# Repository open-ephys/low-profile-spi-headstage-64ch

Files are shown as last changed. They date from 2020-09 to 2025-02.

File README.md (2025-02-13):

# Low-profile SPI Headstage with 64 ephys channels

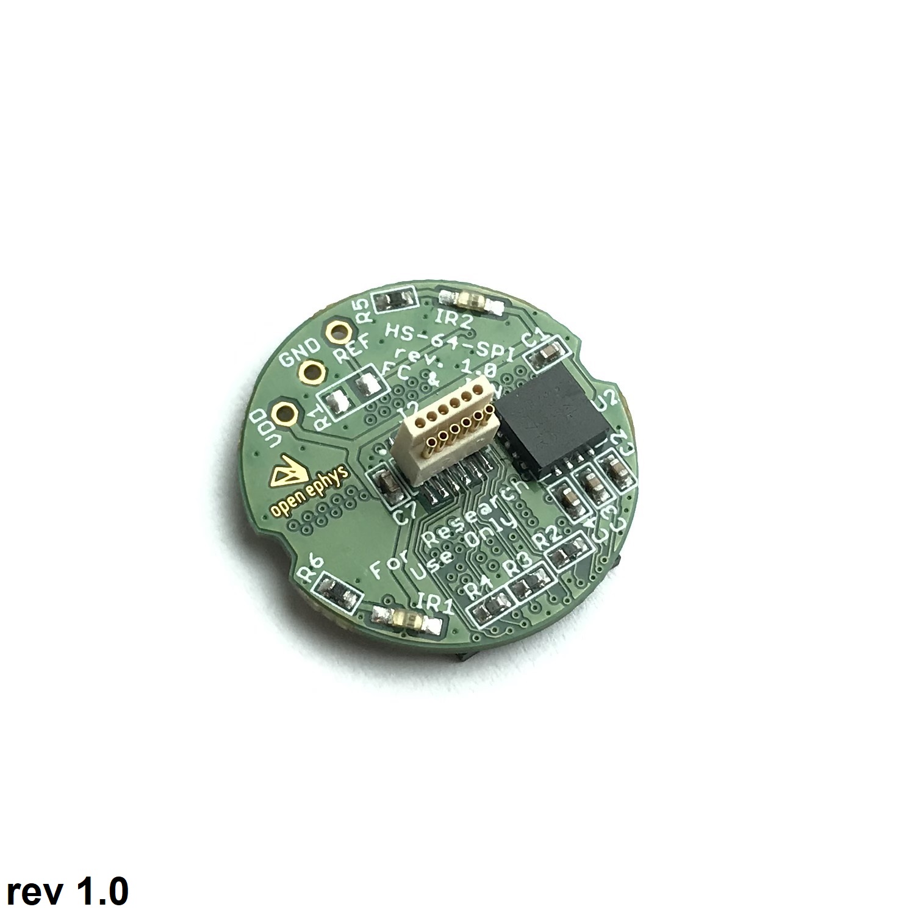
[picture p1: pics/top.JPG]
DeviceTop


## Accelerometer orientation
LP_headstage_top_accelerometer_v1 00

## Licensing

The designs, documentation, and photos available in this repository are free: you can redistribute it and/or modify it under the terms of the used license.
Check file named LICENSE.

Copyright Filipe Carvalho and Jonathan Newman 2020-2022

<br />This work is licensed under a <a rel="license" href="http://creativecommons.org/licenses/by-nc-sa/3.0/igo/">Creative Commons Attribution-NonCommercial-ShareAlike 3.0 IGO License</a>.

If your are interested in obtaining a license to sell this device, please contact info@open-ephys.org

[1]: https://docs.google.com/spreadsheets/d/1aobmmEzBDethzIlrm1eg0eYkBqlyX3s9WbA9KgRwVQI/edit?usp=sharing

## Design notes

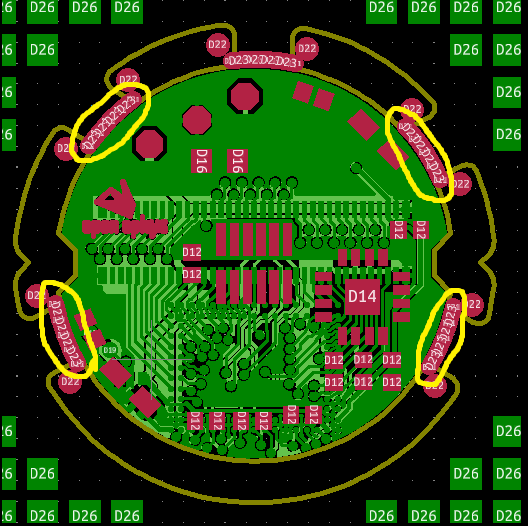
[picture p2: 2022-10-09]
production/mouse bites suggested locations.png

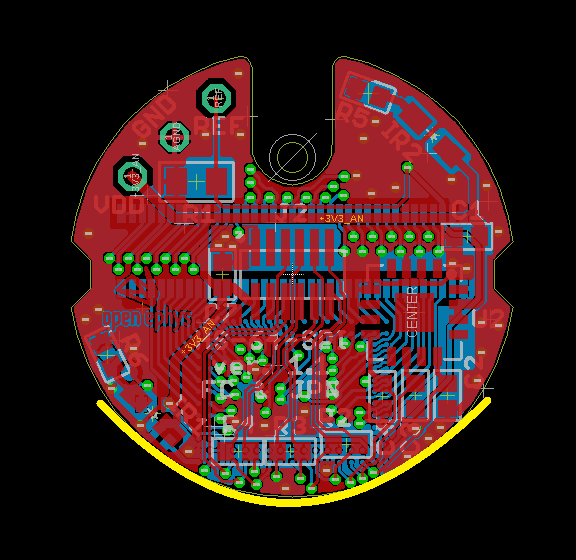
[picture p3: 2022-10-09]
production/mouse bites restriction.png

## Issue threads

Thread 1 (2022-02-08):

Noise

crewl2, 2022-02-08:
I'm getting a ton of noise, I'm wondering if it is coming from the headstage. Should the headstage be grounded?

jonnew, 2022-02-10:
Hi. Yes, it will need to be grounded in order to complete the electrical circuit. I'm not trying to be rude, but you question is indicates that you might need some help setting up your system and understanding the basics of extracellular recordings. I would have a look through this excellent set of materials put together by @ahleighton on how ephys works https://ahleighton.github.io/OE-ephys-course/EEA/theoryday1.html. Also if there is somebody in your lab that has done this type of recording before, I would talk with them about your issue.

Closed 2022-02-10.

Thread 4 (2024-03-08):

Pictures are of v1.0 when current release is v1.1

ChucklesOnGitHub, 2024-03-08:
There is a major difference in GND and REF being connected in v1.1 as opposed to v1.0
And the added cannula hole

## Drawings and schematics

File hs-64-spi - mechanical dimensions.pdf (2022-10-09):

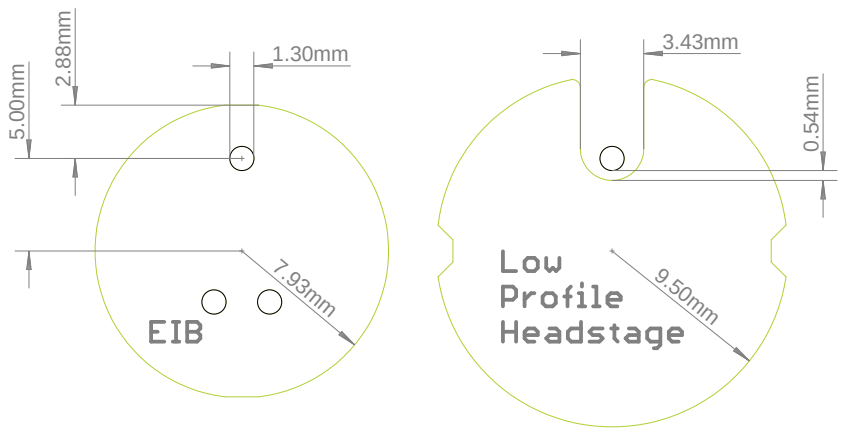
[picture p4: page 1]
9.50mm ³mm

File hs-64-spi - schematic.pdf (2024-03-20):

# AGND AGND ¹

M1

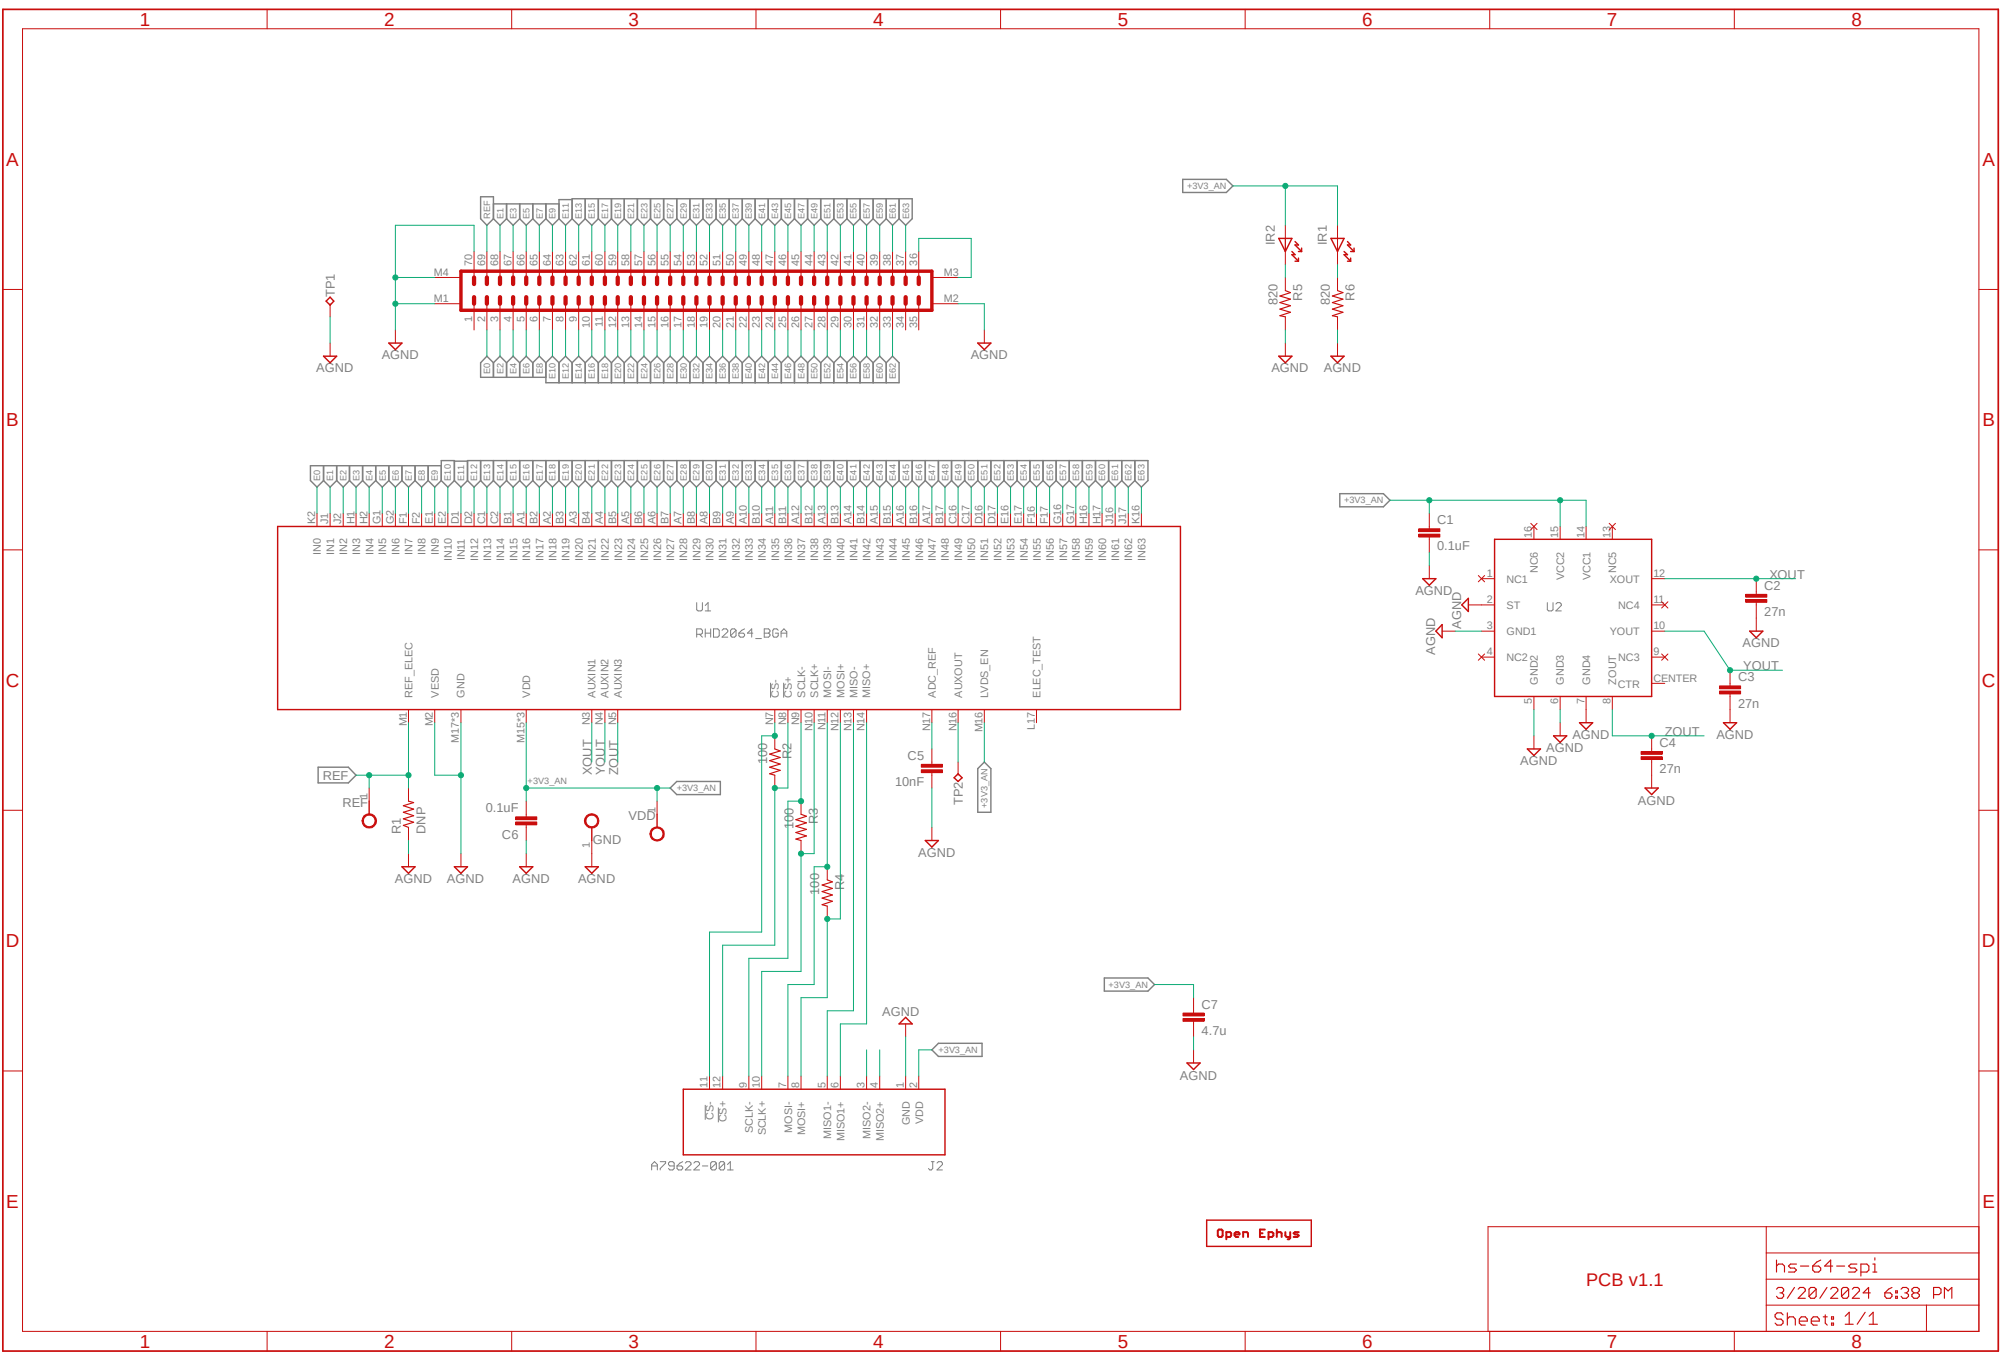
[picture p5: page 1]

8 MOSI- 7 SCLK+ 10 SCLK- 9 VDD

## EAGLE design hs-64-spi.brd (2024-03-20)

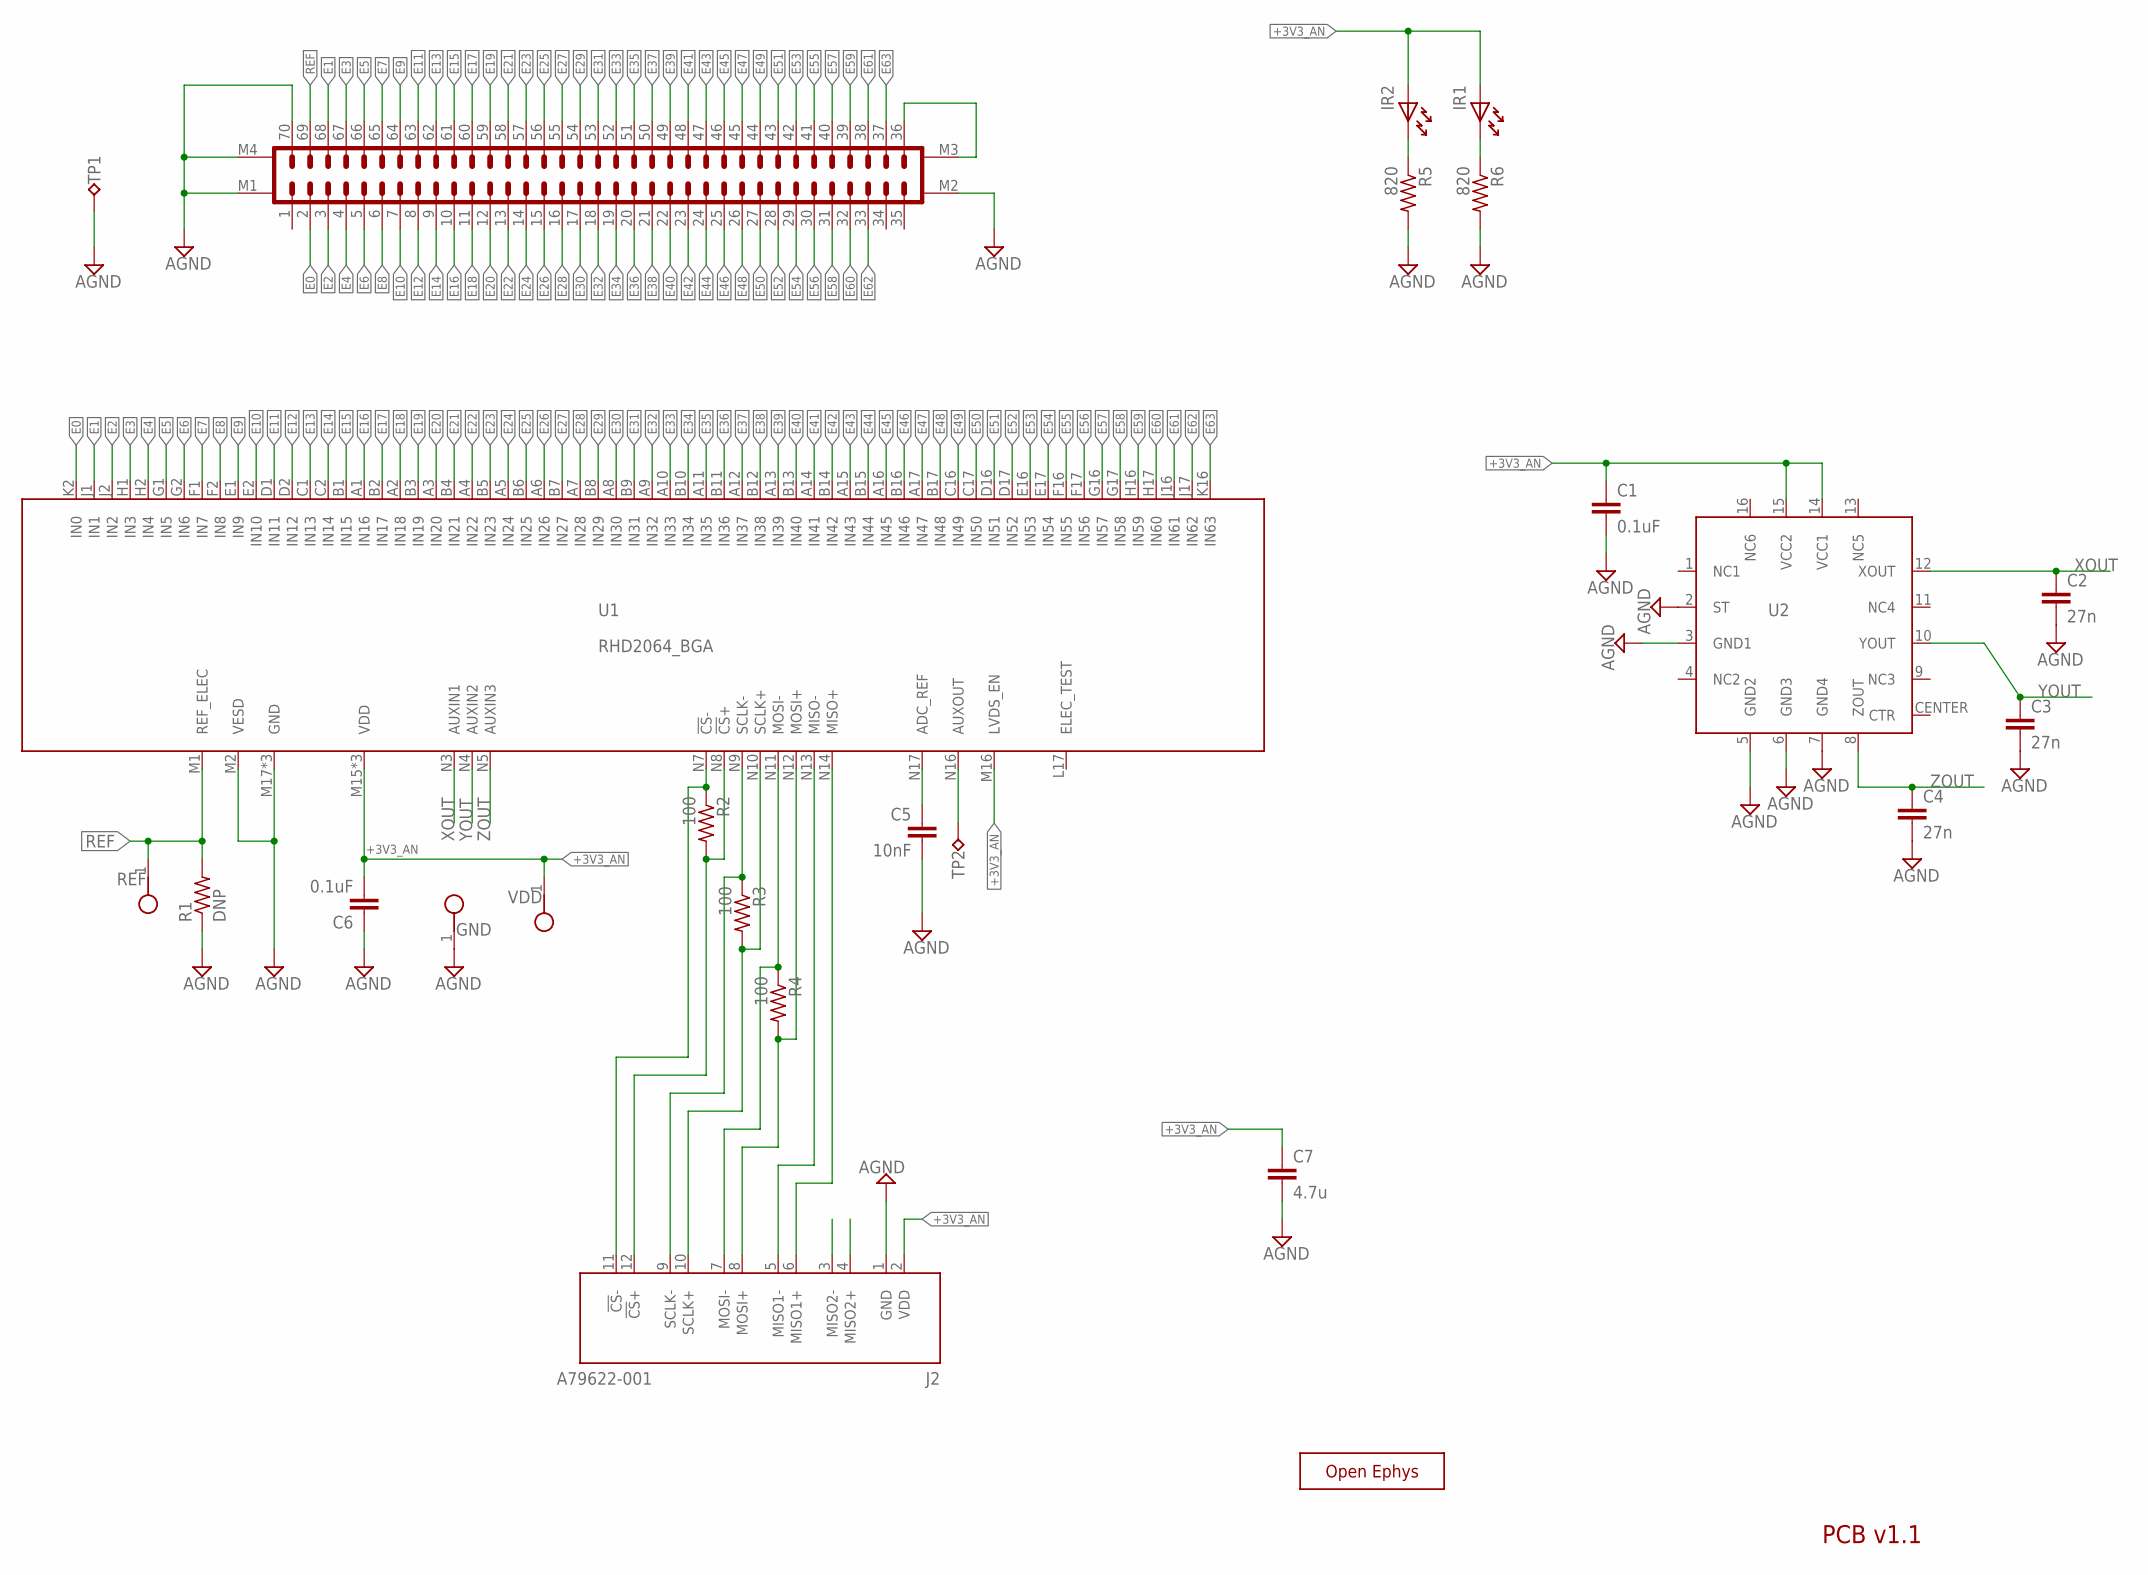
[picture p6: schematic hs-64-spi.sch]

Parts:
C1: 0.1uF; 0402
C2, C3, C4: 27n; 0402
C5: 10nF; 0402T; PARTNO GRM033R71E103KE14D
C6: 0.1uF; 0402T
C7: 4.7u; 0402
GND: TESTPOINT_SMALL
IR1, IR2: LEDHAND; LED_HAND
J1: DF40C-70DP-0.4V(51); DF40-70HEAD-LESS-SILK
J2: A79622-001
R1: DNP; 0603
R2, R3, R4: 100; 0402
R5, R6: 820; 0402
REF: TESTPOINT_SMALL
TP1, TP2: VCC; TP07R
U1: RHD2064_BGA; BGA104_0.5MM
U2: ADXL335_IDAX
VDD: TESTPOINT_SMALL
X: OE-LOGO_3.5X2.5; OE-LOGO-3.5X2.5

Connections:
+3V3_AN: C1.1, C6.2, C7.1, IR1.A, IR2.A, J2.2 (VDD), U1.M15 (VDD), U1.M16 (LVDS_EN), U1.N2 (VDD), U1.N15 (VDD), U2.14 (VCC1), U2.15 (VCC2), VDD.1
AGND: C1.2, C2.2, C3.2, C4.2, C5.2, C6.1, C7.2, GND.1, J1.70, J1.M1, J1.M2, J1.M4, J2.1 (GND), R1.1, R5.2, R6.2, TP1.TP, U1.M2 (VESD), U1.M17 (GND), U1.N1 (GND), U1.N6 (GND), U2.2 (ST), U2.3 (GND1), U2.5 (GND2), U2.6 (GND3), U2.7 (GND4)
E0: J1.2, U1.K2 (IN0)
E1: J1.68, U1.J1 (IN1)
E2: J1.3, U1.J2 (IN2)
E3: J1.67, U1.H1 (IN3)
E4: J1.4, U1.H2 (IN4)
E5: J1.66, U1.G1 (IN5)
E6: J1.5, U1.G2 (IN6)
E7: J1.65, U1.F1 (IN7)
E8: J1.6, U1.F2 (IN8)
E9: J1.64, U1.E1 (IN9)
E10: J1.7, U1.E2 (IN10)
E11: J1.63, U1.D1 (IN11)
E12: J1.8, U1.D2 (IN12)
E13: J1.62, U1.C1 (IN13)
E14: J1.9, U1.C2 (IN14)
E15: J1.61, U1.B1 (IN15)
E16: J1.10, U1.A1 (IN16)
E17: J1.60, U1.B2 (IN17)
E18: J1.11, U1.A2 (IN18)
E19: J1.59, U1.B3 (IN19)
E20: J1.12, U1.A3 (IN20)
E21: J1.58, U1.B4 (IN21)
E22: J1.13, U1.A4 (IN22)
E23: J1.57, U1.B5 (IN23)
E24: J1.14, U1.A5 (IN24)
E25: J1.56, U1.B6 (IN25)
E26: J1.15, U1.A6 (IN26)
E27: J1.55, U1.B7 (IN27)
E28: J1.16, U1.A7 (IN28)
E29: J1.54, U1.B8 (IN29)
E30: J1.17, U1.A8 (IN30)
E31: J1.53, U1.B9 (IN31)
E32: J1.18, U1.A9 (IN32)
E33: J1.52, U1.A10 (IN33)
E34: J1.19, U1.B10 (IN34)
E35: J1.51, U1.A11 (IN35)
E36: J1.20, U1.B11 (IN36)
E37: J1.50, U1.A12 (IN37)
E38: J1.21, U1.B12 (IN38)
E39: J1.49, U1.A13 (IN39)
E40: J1.22, U1.B13 (IN40)
E41: J1.48, U1.A14 (IN41)
E42: J1.23, U1.B14 (IN42)
E43: J1.47, U1.A15 (IN43)
E44: J1.24, U1.B15 (IN44)
E45: J1.46, U1.A16 (IN45)
E46: J1.25, U1.B16 (IN46)
E47: J1.45, U1.A17 (IN47)
E48: J1.26, U1.B17 (IN48)
E49: J1.44, U1.C16 (IN49)
E50: J1.27, U1.C17 (IN50)
E51: J1.43, U1.D16 (IN51)
E52: J1.28, U1.D17 (IN52)
E53: J1.42, U1.E16 (IN53)
E54: J1.29, U1.E17 (IN54)
E55: J1.41, U1.F16 (IN55)
E56: J1.30, U1.F17 (IN56)
E57: J1.40, U1.G16 (IN57)
E58: J1.31, U1.G17 (IN58)
E59: J1.39, U1.H16 (IN59)
E60: J1.32, U1.H17 (IN60)
E61: J1.38, U1.J16 (IN61)
E62: J1.33, U1.J17 (IN62)
E63: J1.37, U1.K16 (IN63)
unnamed: IR2.K, R5.1
unnamed: IR1.K, R6.1
unnamed: C5.1, U1.N17 (ADC_REF)
unnamed: TP2.TP, U1.N16 (AUXOUT)
REF: J1.69, R1.2, REF.1, U1.M1 (REF_ELEC)
RHD_CLK_N: J2.9 (SCLK-), R3.1, U1.N9 (SCLK-)
RHD_CLK_P: J2.10 (SCLK+), R3.2, U1.N10 (SCLK+)
RHD_CS_N: J2.11 (!CS!-), R2.1, U1.N7 (!CS!-)
RHD_CS_P: J2.12 (!CS!+), R2.2, U1.N8 (!CS!+)
RHD_MISO_N: J2.5 (MISO1-), U1.N13 (MISO-)
RHD_MISO_P: J2.6 (MISO1+), U1.N14 (MISO+)
RHD_MOSI_N: J2.7 (MOSI-), R4.1, U1.N11 (MOSI-)
RHD_MOSI_P: J2.8 (MOSI+), R4.2, U1.N12 (MOSI+)
VCOAX: J1.36, J1.M3
XOUT: C2.1, U1.N3 (AUXIN1), U2.12 (XOUT)
YOUT: C3.1, U1.N4 (AUXIN2), U2.10 (YOUT)
ZOUT: C4.1, U1.N5 (AUXIN3), U2.8 (ZOUT)

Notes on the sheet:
PCB v1.1

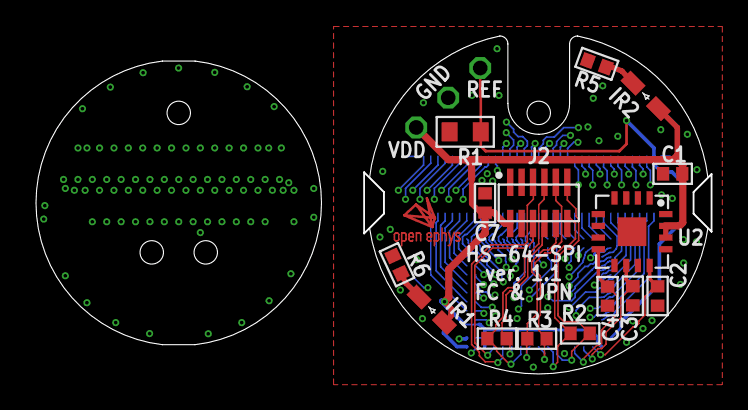
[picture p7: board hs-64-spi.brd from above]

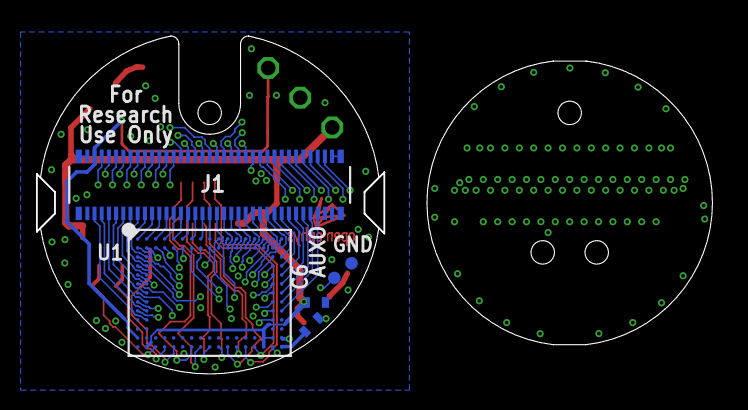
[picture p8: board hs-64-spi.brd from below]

Board: 4 copper layers, 37.5 x 18.8 mm, 25 parts (6 on the bottom side), 83 nets.

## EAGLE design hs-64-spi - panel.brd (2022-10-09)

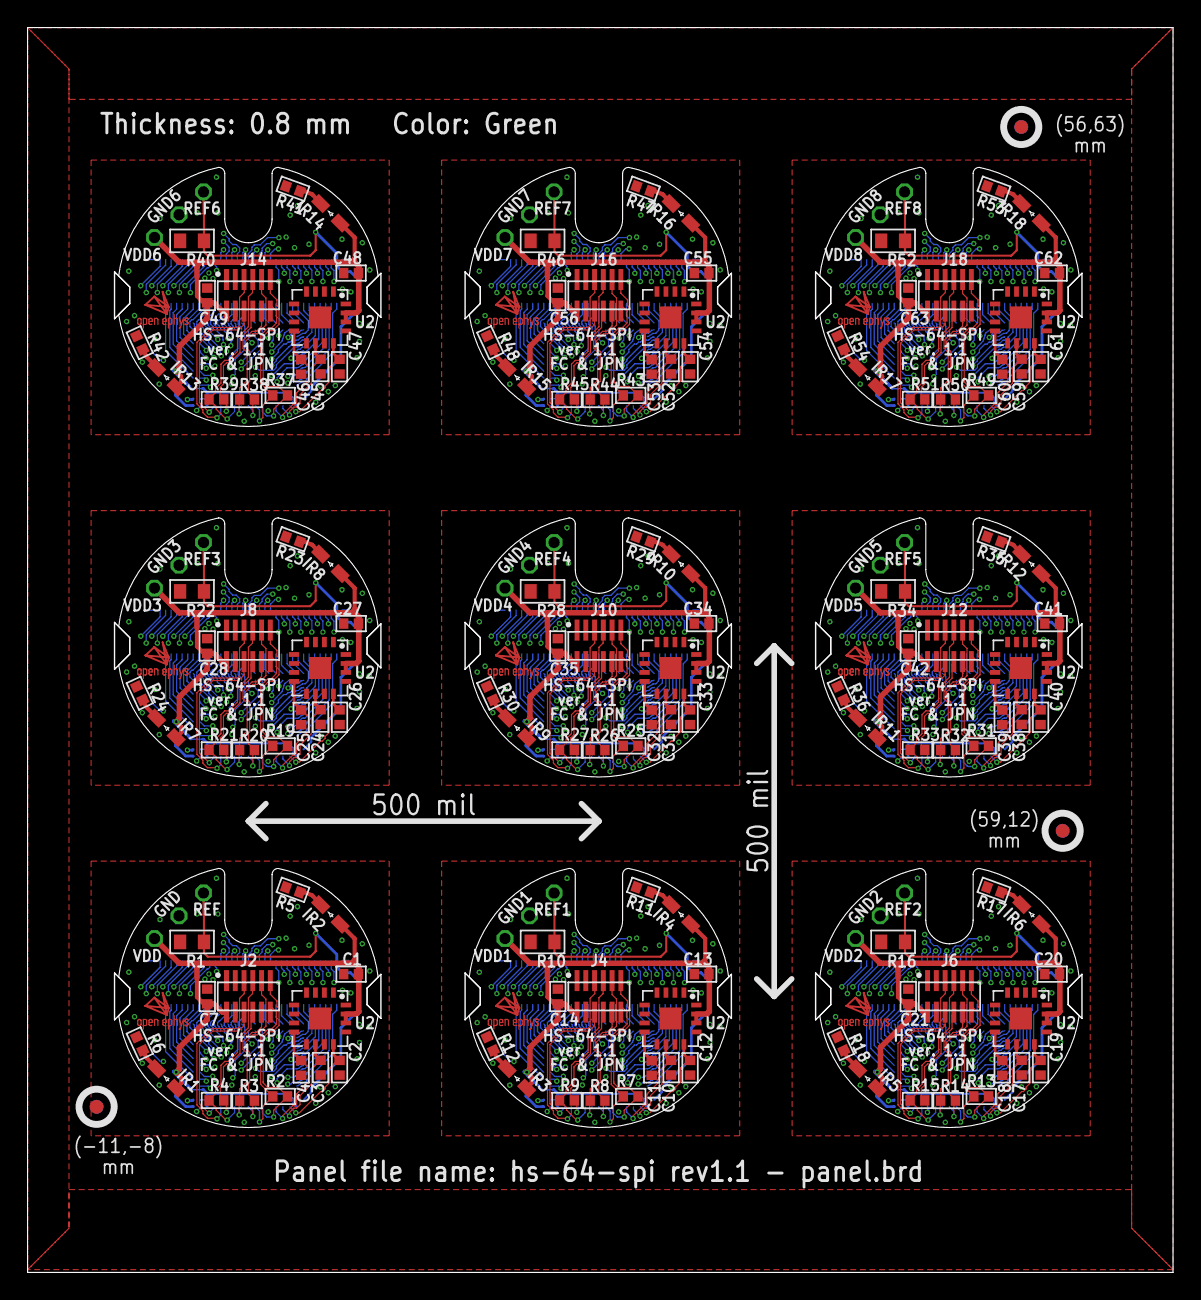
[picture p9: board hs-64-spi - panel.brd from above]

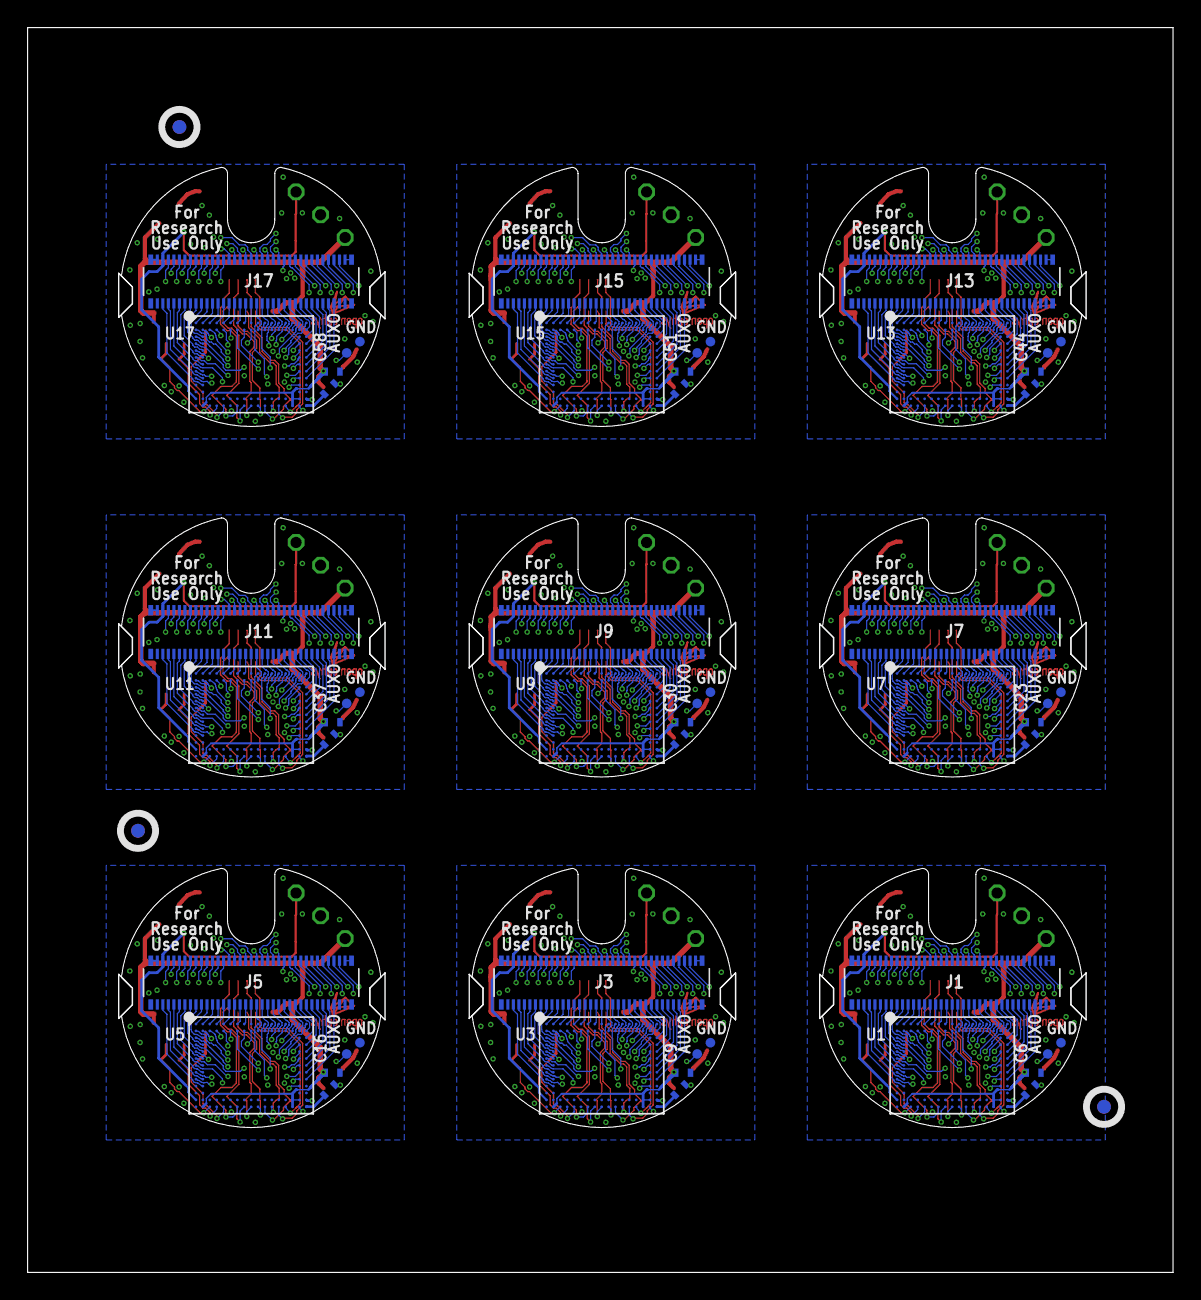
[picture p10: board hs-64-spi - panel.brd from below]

Board: 4 copper layers, 83.0 x 90.2 mm, 231 parts (57 on the bottom side), 747 nets.

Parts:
C1, C13, C20, C27, C34, C41, C48, C55, C62: 0.1uF; 0402
C2, C3, C4, C10, C11, C12, C17, C18, C19, C24, C25, C26, C31, C32, C33, C38, C39, C40, C45, C46, C47, C52, C53, C54, C59, C60, C61: 27n; 0402
C5, C8, C15, C22, C29, C36, C43, C50, C57: 10nF; 0402T
C6, C9, C16, C23, C30, C37, C44, C51, C58: 0.1uF; 0402T
C7, C14, C21, C28, C35, C42, C49, C56, C63: 1u; 0402
E$1, E$2, E$3, E$4, E$5, E$6: FIDUCIAL
GND, GND1, GND2, GND3, GND4, GND5, GND6, GND7, GND8: TESTPOINT_SMALL
IR1, IR2, IR3, IR4, IR5, IR6, IR7, IR8, IR9, IR10, IR11, IR12, IR13, IR14, IR15, IR16, IR17, IR18: LED_HAND
J1, J3, J5, J7, J9, J11, J13, J15, J17: DF40C-70DP-0.4V(51); DF40-70HEAD-LESS-SILK
J2, J4, J6, J8, J10, J12, J14, J16, J18: A79622-001
R1, R10, R16, R22, R28, R34, R40, R46, R52: DNP; 0603
R2, R3, R4, R7, R8, R9, R13, R14, R15, R19, R20, R21, R25, R26, R27, R31, R32, R33, R37, R38, R39, R43, R44, R45, R49, R50, R51: 100; 0402
R5, R6, R11, R12, R17, R18, R23, R24, R29, R30, R35, R36, R41, R42, R47, R48, R53, R54: 820; 0402
REF, REF1, REF2, REF3, REF4, REF5, REF6, REF7, REF8: TESTPOINT_SMALL
TP1, TP2, TP3, TP4, TP5, TP6, TP7, TP8, TP9, TP10, TP11, TP12, TP13, TP14, TP15, TP16, TP17, TP18: VCC; TP07R
U1, U3, U5, U7, U9, U11, U13, U15, U17: RHD2064_BGA; BGA104_0.5MM
U2, U4, U6, U8, U10, U12, U14, U16, U18: ADXL335_IDAX
VDD, VDD1, VDD2, VDD3, VDD4, VDD5, VDD6, VDD7, VDD8: TESTPOINT_SMALL
X, X1, X2, X3, X4, X5, X6, X7, X8: OE-LOGO_3.5X2.5; OE-LOGO-3.5X2.5

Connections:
+3V3_AN: C1.1, C6.2, C7.1, IR1.A, IR2.A, J2.2, U1.M15, U1.M16, U1.N2, U1.N15, U2.14, U2.15, VDD.1
+3V3_AN1: C9.2, C13.1, C14.1, IR3.A, IR4.A, J4.2, U3.M15, U3.M16, U3.N2, U3.N15, U4.14, U4.15, VDD1.1
+3V3_AN2: C16.2, C20.1, C21.1, IR5.A, IR6.A, J6.2, U5.M15, U5.M16, U5.N2, U5.N15, U6.14, U6.15, VDD2.1
+3V3_AN3: C23.2, C27.1, C28.1, IR7.A, IR8.A, J8.2, U7.M15, U7.M16, U7.N2, U7.N15, U8.14, U8.15, VDD3.1
+3V3_AN4: C30.2, C34.1, C35.1, IR9.A, IR10.A, J10.2, U9.M15, U9.M16, U9.N2, U9.N15, U10.14, U10.15, VDD4.1
+3V3_AN5: C37.2, C41.1, C42.1, IR11.A, IR12.A, J12.2, U11.M15, U11.M16, U11.N2, U11.N15, U12.14, U12.15, VDD5.1
+3V3_AN6: C44.2, C48.1, C49.1, IR13.A, IR14.A, J14.2, U13.M15, U13.M16, U13.N2, U13.N15, U14.14, U14.15, VDD6.1
+3V3_AN7: C51.2, C55.1, C56.1, IR15.A, IR16.A, J16.2, U15.M15, U15.M16, U15.N2, U15.N15, U16.14, U16.15, VDD7.1
+3V3_AN8: C58.2, C62.1, C63.1, IR17.A, IR18.A, J18.2, U17.M15, U17.M16, U17.N2, U17.N15, U18.14, U18.15, VDD8.1
AGND6: C1.2, C2.2, C3.2, C4.2, C5.2, C6.1, C7.2, GND.1, J1.70, J1.M1, J1.M2, J1.M4, J2.1, R1.1, R5.2, R6.2, TP1.TP, U1.M2, U1.M17, U1.N1, U1.N6, U2.2, U2.3, U2.5, U2.6, U2.7
AGND7: C8.2, C9.1, C10.2, C11.2, C12.2, C13.2, C14.2, GND1.1, J3.70, J3.M1, J3.M2, J3.M4, J4.1, R10.1, R11.2, R12.2, TP4.TP, U3.M2, U3.M17, U3.N1, U3.N6, U4.2, U4.3, U4.5, U4.6, U4.7
AGND8: C15.2, C16.1, C17.2, C18.2, C19.2, C20.2, C21.2, GND2.1, J5.70, J5.M1, J5.M2, J5.M4, J6.1, R16.1, R17.2, R18.2, TP6.TP, U5.M2, U5.M17, U5.N1, U5.N6, U6.2, U6.3, U6.5, U6.6, U6.7
AGND9: C22.2, C23.1, C24.2, C25.2, C26.2, C27.2, C28.2, GND3.1, J7.70, J7.M1, J7.M2, J7.M4, J8.1, R22.1, R23.2, R24.2, TP8.TP, U7.M2, U7.M17, U7.N1, U7.N6, U8.2, U8.3, U8.5, U8.6, U8.7
AGND10: C29.2, C30.1, C31.2, C32.2, C33.2, C34.2, C35.2, GND4.1, J9.70, J9.M1, J9.M2, J9.M4, J10.1, R28.1, R29.2, R30.2, TP10.TP, U9.M2, U9.M17, U9.N1, U9.N6, U10.2, U10.3, U10.5, U10.6, U10.7
AGND11: C36.2, C37.1, C38.2, C39.2, C40.2, C41.2, C42.2, GND5.1, J11.70, J11.M1, J11.M2, J11.M4, J12.1, R34.1, R35.2, R36.2, TP12.TP, U11.M2, U11.M17, U11.N1, U11.N6, U12.2, U12.3, U12.5, U12.6, U12.7
AGND12: C43.2, C44.1, C45.2, C46.2, C47.2, C48.2, C49.2, GND6.1, J13.70, J13.M1, J13.M2, J13.M4, J14.1, R40.1, R41.2, R42.2, TP14.TP, U13.M2, U13.M17, U13.N1, U13.N6, U14.2, U14.3, U14.5, U14.6, U14.7
AGND13: C50.2, C51.1, C52.2, C53.2, C54.2, C55.2, C56.2, GND7.1, J15.70, J15.M1, J15.M2, J15.M4, J16.1, R46.1, R47.2, R48.2, TP16.TP, U15.M2, U15.M17, U15.N1, U15.N6, U16.2, U16.3, U16.5, U16.6, U16.7
AGND14: C57.2, C58.1, C59.2, C60.2, C61.2, C62.2, C63.2, GND8.1, J17.70, J17.M1, J17.M2, J17.M4, J18.1, R52.1, R53.2, R54.2, TP18.TP, U17.M2, U17.M17, U17.N1, U17.N6, U18.2, U18.3, U18.5, U18.6, U18.7
E0: J1.2, U1.K2
E1: J1.68, U1.J1
E2: J1.3, U1.J2
E3: J1.67, U1.H1
E4: J1.4, U1.H2
E5: J1.66, U1.G1
E6: J1.5, U1.G2
E7: J1.65, U1.F1
E8: J1.6, U1.F2
E9: J1.64, U1.E1
E10: J1.7, U1.E2
E11: J1.63, U1.D1
E12: J1.8, U1.D2
E13: J1.62, U1.C1
E14: J1.9, U1.C2
E15: J1.61, U1.B1
E16: J1.10, U1.A1
E17: J1.60, U1.B2
E18: J1.11, U1.A2
E19: J1.59, U1.B3
E20: J1.12, U1.A3
E21: J1.58, U1.B4
E22: J1.13, U1.A4
E23: J1.57, U1.B5
E24: J1.14, U1.A5
E25: J1.56, U1.B6
E26: J1.15, U1.A6
E27: J1.55, U1.B7
E28: J1.16, U1.A7
E29: J1.54, U1.B8
E30: J1.17, U1.A8
E31: J1.53, U1.B9
E32: J1.18, U1.A9
E33: J1.52, U1.A10
E34: J1.19, U1.B10
E35: J1.51, U1.A11
E36: J1.20, U1.B11
E37: J1.50, U1.A12
E38: J1.21, U1.B12
E39: J1.49, U1.A13
E40: J1.22, U1.B13
E41: J1.48, U1.A14
E42: J1.23, U1.B14
E43: J1.47, U1.A15
E44: J1.24, U1.B15
E45: J1.46, U1.A16
E46: J1.25, U1.B16
E47: J1.45, U1.A17
E48: J1.26, U1.B17
E49: J1.44, U1.C16
E50: J1.27, U1.C17
E51: J1.43, U1.D16
E52: J1.28, U1.D17
E53: J1.42, U1.E16
E54: J1.29, U1.E17
E55: J1.41, U1.F16
E56: J1.30, U1.F17
E57: J1.40, U1.G16
E58: J1.31, U1.G17
E59: J1.39, U1.H16
E60: J1.32, U1.H17
E61: J1.38, U1.J16
E62: J1.33, U1.J17
E63: J1.37, U1.K16
E64: J3.17, U3.A8
E65: J3.54, U3.B8
E66: J3.16, U3.A7
E67: J3.55, U3.B7
E68: J3.15, U3.A6
E69: J3.56, U3.B6
E70: J3.14, U3.A5
E71: J3.57, U3.B5
E72: J3.13, U3.A4
E73: J3.58, U3.B4
E74: J3.12, U3.A3
E75: J3.59, U3.B3
E76: J3.11, U3.A2
E77: J3.60, U3.B2
E78: J3.10, U3.A1
E79: J3.61, U3.B1
E80: J3.9, U3.C2
E81: J3.62, U3.C1
E82: J3.8, U3.D2
E83: J3.63, U3.D1
E84: J3.7, U3.E2
E85: J3.64, U3.E1
E86: J3.6, U3.F2
E87: J3.65, U3.F1
E88: J3.5, U3.G2
E89: J3.66, U3.G1
E90: J3.4, U3.H2
E91: J3.67, U3.H1
E92: J3.3, U3.J2
E93: J3.68, U3.J1
E94: J3.2, U3.K2
E95: J3.53, U3.B9
E96: J3.52, U3.A10
E97: J3.19, U3.B10
E98: J3.51, U3.A11
E99: J3.20, U3.B11
E100: J3.50, U3.A12
E101: J3.21, U3.B12
E102: J3.49, U3.A13
E103: J3.22, U3.B13
E104: J3.48, U3.A14
E105: J3.23, U3.B14
E106: J3.47, U3.A15
E107: J3.24, U3.B15
E108: J3.46, U3.A16
E109: J3.25, U3.B16
E110: J3.45, U3.A17
E111: J3.26, U3.B17
E112: J3.44, U3.C16
E113: J3.27, U3.C17
E114: J3.43, U3.D16
E115: J3.28, U3.D17
E116: J3.42, U3.E16
E117: J3.29, U3.E17
E118: J3.41, U3.F16
E119: J3.30, U3.F17
E120: J3.40, U3.G16
E121: J3.31, U3.G17
E122: J3.39, U3.H16
E123: J3.32, U3.H17
E124: J3.38, U3.J16
E125: J3.33, U3.J17
E126: J3.37, U3.K16
E127: J3.18, U3.A9
E128: J5.17, U5.A8
E129: J5.54, U5.B8
E130: J5.16, U5.A7
E131: J5.55, U5.B7
E132: J5.15, U5.A6
E133: J5.56, U5.B6
E134: J5.14, U5.A5
E135: J5.57, U5.B5
E136: J5.13, U5.A4
E137: J5.58, U5.B4
E138: J5.12, U5.A3
E139: J5.59, U5.B3
E140: J5.11, U5.A2
E141: J5.60, U5.B2
E142: J5.10, U5.A1
E143: J5.61, U5.B1
E144: J5.9, U5.C2
E145: J5.62, U5.C1
E146: J5.8, U5.D2
E147: J5.63, U5.D1
E148: J5.7, U5.E2
E149: J5.64, U5.E1
E150: J5.6, U5.F2
E151: J5.65, U5.F1
E152: J5.5, U5.G2
E153: J5.66, U5.G1
E154: J5.4, U5.H2
E155: J5.67, U5.H1
E156: J5.3, U5.J2
E157: J5.68, U5.J1
E158: J5.2, U5.K2
E159: J5.53, U5.B9
E160: J5.52, U5.A10
E161: J5.19, U5.B10
E162: J5.51, U5.A11
E163: J5.20, U5.B11
E164: J5.50, U5.A12
E165: J5.21, U5.B12
E166: J5.49, U5.A13
E167: J5.22, U5.B13
E168: J5.48, U5.A14
E169: J5.23, U5.B14
E170: J5.47, U5.A15
E171: J5.24, U5.B15
E172: J5.46, U5.A16
E173: J5.25, U5.B16
E174: J5.45, U5.A17
E175: J5.26, U5.B17
E176: J5.44, U5.C16
E177: J5.27, U5.C17
E178: J5.43, U5.D16
E179: J5.28, U5.D17
E180: J5.42, U5.E16
E181: J5.29, U5.E17
E182: J5.41, U5.F16
E183: J5.30, U5.F17
E184: J5.40, U5.G16
E185: J5.31, U5.G17
E186: J5.39, U5.H16
E187: J5.32, U5.H17
E188: J5.38, U5.J16
E189: J5.33, U5.J17
E190: J5.37, U5.K16
E191: J5.18, U5.A9
E192: J7.17, U7.A8
E193: J7.54, U7.B8
E194: J7.16, U7.A7
E195: J7.55, U7.B7
E196: J7.15, U7.A6
E197: J7.56, U7.B6
E198: J7.14, U7.A5
E199: J7.57, U7.B5
E200: J7.13, U7.A4
E201: J7.58, U7.B4
E202: J7.12, U7.A3
E203: J7.59, U7.B3
E204: J7.11, U7.A2
E205: J7.60, U7.B2
E206: J7.10, U7.A1
E207: J7.61, U7.B1
E208: J7.9, U7.C2
E209: J7.62, U7.C1
E210: J7.8, U7.D2
E211: J7.63, U7.D1
E212: J7.7, U7.E2
E213: J7.64, U7.E1
E214: J7.6, U7.F2
E215: J7.65, U7.F1
E216: J7.5, U7.G2
E217: J7.66, U7.G1
E218: J7.4, U7.H2
E219: J7.67, U7.H1
E220: J7.3, U7.J2
E221: J7.68, U7.J1
E222: J7.2, U7.K2
E223: J7.53, U7.B9
E224: J7.52, U7.A10
E225: J7.19, U7.B10
E226: J7.51, U7.A11
E227: J7.20, U7.B11
E228: J7.50, U7.A12
E229: J7.21, U7.B12
E230: J7.49, U7.A13
E231: J7.22, U7.B13
E232: J7.48, U7.A14
E233: J7.23, U7.B14
E234: J7.47, U7.A15
E235: J7.24, U7.B15
E236: J7.46, U7.A16
E237: J7.25, U7.B16
E238: J7.45, U7.A17
E239: J7.26, U7.B17
E240: J7.44, U7.C16
E241: J7.27, U7.C17
E242: J7.43, U7.D16
E243: J7.28, U7.D17
E244: J7.42, U7.E16
E245: J7.29, U7.E17
E246: J7.41, U7.F16
E247: J7.30, U7.F17
E248: J7.40, U7.G16
E249: J7.31, U7.G17
E250: J7.39, U7.H16
E251: J7.32, U7.H17
E252: J7.38, U7.J16
E253: J7.33, U7.J17
E254: J7.37, U7.K16
E255: J7.18, U7.A9
E256: J9.17, U9.A8
E257: J9.54, U9.B8
E258: J9.16, U9.A7
E259: J9.55, U9.B7
E260: J9.15, U9.A6
E261: J9.56, U9.B6
E262: J9.14, U9.A5
E263: J9.57, U9.B5
E264: J9.13, U9.A4
E265: J9.58, U9.B4
E266: J9.12, U9.A3
E267: J9.59, U9.B3
E268: J9.11, U9.A2
E269: J9.60, U9.B2
E270: J9.10, U9.A1
E271: J9.61, U9.B1
E272: J9.9, U9.C2
E273: J9.62, U9.C1
E274: J9.8, U9.D2
E275: J9.63, U9.D1
E276: J9.7, U9.E2
E277: J9.64, U9.E1
E278: J9.6, U9.F2
E279: J9.65, U9.F1
E280: J9.5, U9.G2
E281: J9.66, U9.G1
E282: J9.4, U9.H2
E283: J9.67, U9.H1
E284: J9.3, U9.J2
E285: J9.68, U9.J1
E286: J9.2, U9.K2
E287: J9.53, U9.B9
E288: J9.52, U9.A10
E289: J9.19, U9.B10
E290: J9.51, U9.A11
E291: J9.20, U9.B11
E292: J9.50, U9.A12
E293: J9.21, U9.B12
E294: J9.49, U9.A13
E295: J9.22, U9.B13
E296: J9.48, U9.A14
E297: J9.23, U9.B14
E298: J9.47, U9.A15
E299: J9.24, U9.B15
E300: J9.46, U9.A16
E301: J9.25, U9.B16
E302: J9.45, U9.A17
E303: J9.26, U9.B17
E304: J9.44, U9.C16
E305: J9.27, U9.C17
E306: J9.43, U9.D16
E307: J9.28, U9.D17
E308: J9.42, U9.E16
E309: J9.29, U9.E17
E310: J9.41, U9.F16
E311: J9.30, U9.F17
E312: J9.40, U9.G16
E313: J9.31, U9.G17
E314: J9.39, U9.H16
E315: J9.32, U9.H17
E316: J9.38, U9.J16
E317: J9.33, U9.J17
E318: J9.37, U9.K16
E319: J9.18, U9.A9
E320: J11.17, U11.A8
E321: J11.54, U11.B8
E322: J11.16, U11.A7
E323: J11.55, U11.B7
E324: J11.15, U11.A6
E325: J11.56, U11.B6
E326: J11.14, U11.A5
E327: J11.57, U11.B5
E328: J11.13, U11.A4
E329: J11.58, U11.B4
E330: J11.12, U11.A3
E331: J11.59, U11.B3
E332: J11.11, U11.A2
E333: J11.60, U11.B2
E334: J11.10, U11.A1
E335: J11.61, U11.B1
E336: J11.9, U11.C2
E337: J11.62, U11.C1
E338: J11.8, U11.D2
E339: J11.63, U11.D1
E340: J11.7, U11.E2
E341: J11.64, U11.E1
E342: J11.6, U11.F2
E343: J11.65, U11.F1
E344: J11.5, U11.G2
E345: J11.66, U11.G1
E346: J11.4, U11.H2
E347: J11.67, U11.H1
E348: J11.3, U11.J2
E349: J11.68, U11.J1
E350: J11.2, U11.K2
E351: J11.53, U11.B9
E352: J11.52, U11.A10
E353: J11.19, U11.B10
E354: J11.51, U11.A11
E355: J11.20, U11.B11
E356: J11.50, U11.A12
E357: J11.21, U11.B12
E358: J11.49, U11.A13
E359: J11.22, U11.B13
E360: J11.48, U11.A14
E361: J11.23, U11.B14
E362: J11.47, U11.A15
E363: J11.24, U11.B15
E364: J11.46, U11.A16
E365: J11.25, U11.B16
E366: J11.45, U11.A17
E367: J11.26, U11.B17
E368: J11.44, U11.C16
E369: J11.27, U11.C17
E370: J11.43, U11.D16
E371: J11.28, U11.D17
E372: J11.42, U11.E16
E373: J11.29, U11.E17
E374: J11.41, U11.F16
E375: J11.30, U11.F17
E376: J11.40, U11.G16
E377: J11.31, U11.G17
E378: J11.39, U11.H16
E379: J11.32, U11.H17
E380: J11.38, U11.J16
E381: J11.33, U11.J17
E382: J11.37, U11.K16
E383: J11.18, U11.A9
E384: J13.17, U13.A8
E385: J13.54, U13.B8
E386: J13.16, U13.A7
E387: J13.55, U13.B7
E388: J13.15, U13.A6
E389: J13.56, U13.B6
E390: J13.14, U13.A5
E391: J13.57, U13.B5
E392: J13.13, U13.A4
E393: J13.58, U13.B4
E394: J13.12, U13.A3
E395: J13.59, U13.B3
E396: J13.11, U13.A2
E397: J13.60, U13.B2
E398: J13.10, U13.A1
E399: J13.61, U13.B1
E400: J13.9, U13.C2
E401: J13.62, U13.C1
E402: J13.8, U13.D2
E403: J13.63, U13.D1
E404: J13.7, U13.E2
E405: J13.64, U13.E1
E406: J13.6, U13.F2
E407: J13.65, U13.F1
E408: J13.5, U13.G2
E409: J13.66, U13.G1
E410: J13.4, U13.H2
E411: J13.67, U13.H1
E412: J13.3, U13.J2
E413: J13.68, U13.J1
E414: J13.2, U13.K2
E415: J13.53, U13.B9
E416: J13.52, U13.A10
E417: J13.19, U13.B10
E418: J13.51, U13.A11
E419: J13.20, U13.B11
E420: J13.50, U13.A12
E421: J13.21, U13.B12
E422: J13.49, U13.A13
E423: J13.22, U13.B13
E424: J13.48, U13.A14
E425: J13.23, U13.B14
E426: J13.47, U13.A15
E427: J13.24, U13.B15
E428: J13.46, U13.A16
E429: J13.25, U13.B16
E430: J13.45, U13.A17
E431: J13.26, U13.B17
E432: J13.44, U13.C16
E433: J13.27, U13.C17
E434: J13.43, U13.D16
E435: J13.28, U13.D17
E436: J13.42, U13.E16
E437: J13.29, U13.E17
E438: J13.41, U13.F16
E439: J13.30, U13.F17
E440: J13.40, U13.G16
E441: J13.31, U13.G17
E442: J13.39, U13.H16
E443: J13.32, U13.H17
E444: J13.38, U13.J16
E445: J13.33, U13.J17
E446: J13.37, U13.K16
E447: J13.18, U13.A9
E448: J15.17, U15.A8
E449: J15.54, U15.B8
E450: J15.16, U15.A7
E451: J15.55, U15.B7
E452: J15.15, U15.A6
E453: J15.56, U15.B6
E454: J15.14, U15.A5
E455: J15.57, U15.B5
E456: J15.13, U15.A4
E457: J15.58, U15.B4
E458: J15.12, U15.A3
E459: J15.59, U15.B3
E460: J15.11, U15.A2
E461: J15.60, U15.B2
E462: J15.10, U15.A1
E463: J15.61, U15.B1
E464: J15.9, U15.C2
E465: J15.62, U15.C1
E466: J15.8, U15.D2
E467: J15.63, U15.D1
E468: J15.7, U15.E2
E469: J15.64, U15.E1
E470: J15.6, U15.F2
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

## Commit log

2020-09-03 Added the PCB design files.
    [hs-64-spi rev1.0 - panel.brd, hs-64-spi rev1.0.brd, hs-64-spi rev1.0.sch]
2020-09-03 Added production files.
    [hs-64-spi rev1.0_centroid.csv]
2022-10-09 Added PCB design files for the new version 1.1.
    [hs-64-spi - panel.brd, hs-64-spi.brd, hs-64-spi.sch]
2022-10-09 Added fiducials on bottom.
    [hs-64-spi - panel.brd]
2022-10-09 Updated mechanical dimensions.
    [hs-64-spi.brd]
2022-11-14 Added drill files.
2023-01-09 Add R1 to assembly.
    [hs-64-spi_centroid.csv]
2023-07-06 added accelerometer orientation
2023-10-07 Corrected C7 value to 4.7uF.
    [hs-64-spi.brd, hs-64-spi.sch]
2024-03-20 Updated Hirose (J1) schematic.
    [hs-64-spi.brd, hs-64-spi.sch]
2025-02-13 Reorganize gerber files.
    [hs-64-spi - panel.drl]

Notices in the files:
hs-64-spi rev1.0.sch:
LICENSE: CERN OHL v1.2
